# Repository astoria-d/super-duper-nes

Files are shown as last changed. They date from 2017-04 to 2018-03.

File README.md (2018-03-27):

# super-duper-nes

==========  Super-duper NES project!  ==========

This is a project that extends NES (Nintendo Entertainment System) with FPGA (DE0-CV board).

Architecture:
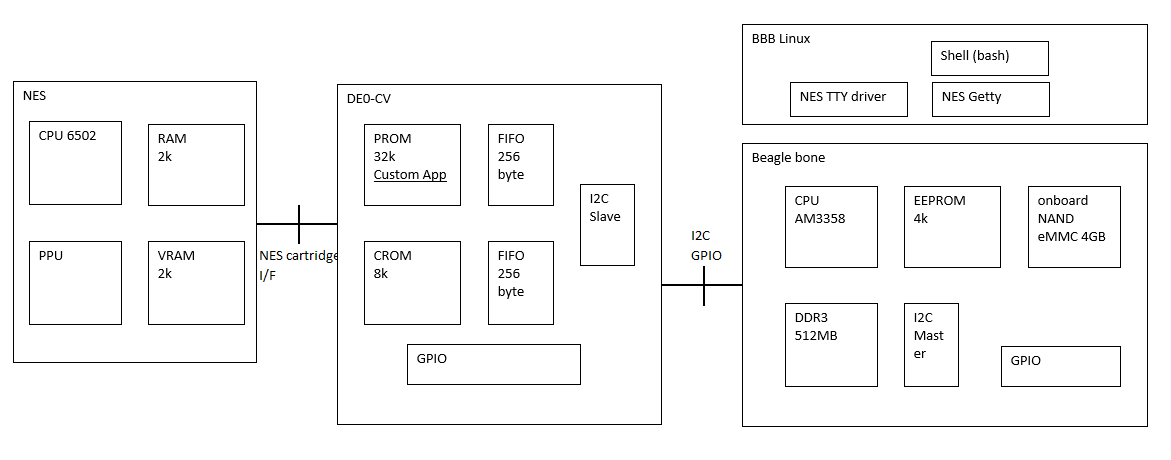
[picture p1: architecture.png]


User application ROM is deployed on FPGA ROM area. NES and DE0-CV board is connected through the NES 60 pin connector. User application has the Linux console screen. FPGA then has the I2C controler that connects FPGA and Linux board (Beagle bone black SBC). This will enable controling Linux from NES.

Demo:

<a href="http://www.youtube.com/watch?feature=player_embedded&v=RXIwD2YRAUA" target="_blank">super duper nes demo</a>

https://youtu.be/RXIwD2YRAUA

It can extend NES capability to infinity!

--astoria-d

-------

# source tree:
  
    top  
    |-- circuit-diagram             (obsolete)  
    |-- doc                         Technical documents.  
    |   |-- craft-work-diary        Electronic handcrafts pictures  
    |   |   |-- yyyymmdd  
    |   |   |-- ....  
    |   |   `-- yyyymmdd  
    |   `-- memo                    Linux work memo  
    |-- duper_cartridge             NES FPGA cartridge implementation (ROM, I2C slave, FIFO etc.)  
    |   `-- simulation              Modelsim scripts  
    |-- duper_linux                 Linux modules  
    |   |-- bbb_tty                 NES tty driver for BBB  
    |   |-- nes_shell  
    |   `-- tools  
    |-- duper_mapper                motonesemu mapper module.  
    |-- duper_rom                   NES cardridge ROM code  
    `-- test

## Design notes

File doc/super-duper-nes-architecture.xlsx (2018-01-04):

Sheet: overview
 |  | IDE 40 pins flat cable I/F
 | Fami con cartlidge I/F |  | I2C
 | 60 pin 2.54 mm pitch
 | dual side card edge
AV out

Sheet: block diagram
NES cartridge | I2C
I/F | GPIO

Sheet: memory map
CPU space | 0x10000
memory map | 0xfffa |  | reset vector
 | 0xfff8 |  | duper io reg | 0xfff9 | w: push fifo register
 |  |  |  |  | r: pop fifo register
 |  |  | prog rom | 0xfff8 | fifo status register
 |  |  | upper bank
 | 0xc000
 |  |  |  |  | firo status register
 |  |  |  | bit
 |  |  | prog rom | 0 | write fifo empty
 |  |  | lower bank | 1 | write fifo full
 |  |  |  | 2 | always 0
 | 0x8000 |  |  | 3 | always 0
 |  |  |  | 4 | read fifo empty
 |  |  | sram | 5 | read fifo full
 | 0x6000 |  |  | 6 | always 0
 |  |  |  | 7 | always 0
 |  |  | expantion rom
 | 0x4020
 | 0x4000 |  | io reg
 |  |  | mirror
 |  |  | 0x2000-0x2007
 | 0x2008
 | 0x2000 |  | io reg
 |  |  | mirror
 |  |  | 0x0000-0x07ff
 | 0x0800
 | 0x0200 |  | ram
 | 0x0100 | stack
 | 0x0000 | zp

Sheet: board-inter-connect
 |  |  |  |  |  |  |  |  |  |  |  |  | DE1
NES
 |  |  | FRONT |  |  | BACK
 |  |  | 1:GND | x | x | 31:Vcc
 | x | 2:PRG-A11 | 2:PRG-A11 | x | x | 32:M2
 | x | 3:PRG-A10 | 3:PRG-A10 | x | x | 33:PRG-A12 |  |  | x | 33:PRG-A12
 | x | 4:PRG-A9 | 4:PRG-A9 | x | x | 34:PRG-A13 |  |  | x | 34:PRG-A13
 | x | 5:PRG-A8 | 5:PRG-A8 | x | x | 35:PRG-A14 |  |  | x | 35:PRG-A14
 | x | 6:PRG-A7 | 6:PRG-A7 | x | x | 36:PRG-D7 |  | x | 36:PRG-D7 |  |  |  |  | i2c_sda | i2c_scl | NC | NC | NC | 3.3V | 47:~CHR-WE | 50:CHR-A7 | 51:CHR-A8 | 52:CHR-A9 | 53:CHR-A10 | 54:CHR-A11 | 55:CHR-A12 | 56~:CHR-A13 | 5v | NC | 57:CHR-D7 | 58:CHR-D6 | 59:CHR-D5 | 60:CHR-D4
 | x | 7:PRG-A6 | 7:PRG-A6 | x | x | 37:PRG-D6 |  | x | 37:PRG-D6 |  | x | 32:M2 |  | x | x | x | x | x | x | x | x | x | x | x | x | x | x | x | x | x | x | x | x
 | x | 8:PRG-A5 | 8:PRG-A5 | x | x | 38:PRG-D5 |  | x | 38:PRG-D5 |  | x | 44:~PRG-CE |  | x | x | x | x | x | x | x | x | x | x | x | x | x | x | x | x | x | x | x | x
 | x | 9:PRG-A4 | 9:PRG-A4 | x | x | 39:PRG-D4 |  | x | 39:PRG-D4 |  |  |  |  | bbb_f_empty | nes_f_full | NC | NC | NC | GND | 17:~CHR-OE | 19:CHR-A6 | 20:CHR-A5 | 21:CHR-A4 | 22:CHR-A3 | 23:CHR-A2 | 24:CHR-A1 | 25:CHR-A0 | GND | NC | 29:CHR-D0 | 28:CHR-D1 | 27:CHR-D2 | 26:CHR-D3
x | 10:PRG-A3 |  | 10:PRG-A3 | x | x | 40:PRG-D3 |  | x | 40:PRG-D3
x | 11:PRG-A2 |  | 11:PRG-A2 | x | x | 41:PRG-D2 |  | x | 41:PRG-D2
x | 12:PRG-A1 |  | 12:PRG-A1 | x | x | 42:PRG-D1 |  | x | 42:PRG-D1 |  |  |  |  | NC | NC | NC | NC | 44:~PRG-CE | 3.3V | 2:PRG-A11 | 3:PRG-A10 | 4:PRG-A9 | 5:PRG-A8 | 6:PRG-A7 | 7:PRG-A6 | 8:PRG-A5 | 9:PRG-A4 | 5v | NC | 36:PRG-D7 | 37:PRG-D6 | 38:PRG-D5 | 39:PRG-D4
x | 13:PRG-A0 |  | 13:PRG-A0 | x | x | 43:PRG-D0 |  | x | 43:PRG-D0 |  |  | i2c_sda |  | 34 | 32 | 30 | 28 | 26 |  | 24 | 22 | 20 | 18 | 16 | 14 | 12 | 10 |  | 8 | 6 | 4 | 2 | 0
x | 14:PRG-R/~W |  | 14:PRG-R/~W | x | x | 44:~PRG-CE |  |  |  |  |  | i2c_scl
 |  |  | 15:~IRQ N/C (Out) | x | x | 45:Sound In C46 |  |  |  |  |  |  |  | x | x | x | x | x | x | x | x | x | x | x | x | x | x | x | x | x | x | x | x
 |  |  | 16:GND | x | x | 46:Sound Out C45 |  |  |  |  |  |  |  | x | x | x | x | x | x | x | x | x | x | x | x | x | x | x | x | x | x | x | x
 |  |  | 17:~CHR-OE | x | x | 47:~CHR-WE
 |  |  | 18:VRAM-A10 | x | x | 48:~VRAM-CE |  |  |  |  |  |  |  | 35 | 33 | 31 | 29 | 27 |  | 25 | 23 | 21 | 19 | 17 | 15 | 13 | 11 |  | 9 | 7 | 5 | 3 | 1
 | x | 17:~CHR-OE | 19:CHR-A6 | x | x | 49:CHR-A13 |  |  | 47:~CHR-WE |  |  |  |  | NC | NC | NC | NC | 32:M2 | GND | 10:PRG-A3 | 11:PRG-A2 | 12:PRG-A1 | 13:PRG-A0 | 14:PRG-R/~W | 35:PRG-A14 | 34:PRG-A13 | 35:PRG-A12 | GND | NC | 40:PRG-D3 | 41:PRG-D2 | 42:PRG-D1 | 43:PRG-D0
 | x | 19:CHR-A6 | 20:CHR-A5 | x | x | 50:CHR-A7 |  |  | 50:CHR-A7
 | x | 20:CHR-A5 | 21:CHR-A4 | x | x | 51:CHR-A8 |  |  | 51:CHR-A8
 | x | 21:CHR-A4 | 22:CHR-A3 | x | x | 52:CHR-A9 |  |  | 52:CHR-A9
 | x | 22:CHR-A3 | 23:CHR-A2 | x | x | 53:CHR-A10 |  | x | 53:CHR-A10
 | x | 23:CHR-A2 | 24:CHR-A1 | x | x | 54:CHR-A11 |  | x | 54:CHR-A11
 | x | 24:CHR-A1 | 25:CHR-A0 | x | x | 55:CHR-A12 |  | x | 55:CHR-A12
 | x | 25:CHR-A0 | 26:CHR-D0 | x | x | 56~:CHR-A13 |  | x | 56~:CHR-A13
x |  | 26:CHR-D0 | 27:CHR-D1 | x | x | 57:CHR-D7 | x |  | 57:CHR-D7
x |  | 27:CHR-D1 | 28:CHR-D2 | x | x | 58:CHR-D6 | x |  | 58:CHR-D6
x |  | 28:CHR-D2 | 29:CHR-D3 | x | x | 59:CHR-D5 | x |  | 59:CHR-D5
x |  | 29:CHR-D3 | 30:Vcc | x | x | 60:CHR-D4 | x |  | 60:CHR-D4

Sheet: bus
 | /data
 | /addr
 |  | /i2c_data_in | /empty | /full
 |  | /i2c_data_out
 |  | /scl | /full | /empty
 |  | /sda
 | /data
 | /addr
/composite

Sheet: duper cartridge rtl
 |  |  |  | linux command send |  |  |  |  |  |  |  |  |  |  |  |  |  |  |  |  |  |  |  |  |  |  | linux terminal
 |  |  |  | console display |  |  |  |  |  |  |  |  |  |  |  |  |  |  |  |  |  |  |  |  |  |  | i2c i/o
 | composite out |  |  |  |  |  |  |  | rom read |  |  |  |  |  |  |  |  |  | fifo status read (gpio)
 |  |  |  |  |  |  |  |  | fifo status read |  |  |  |  |  |  |  |  |  | i2c data read
 |  |  |  |  |  |  |  |  | fifo read |  |  |  |  |  |  |  |  |  | i2c data write
 | keypad input |  |  |  |  |  |  |  | fifo write
 |  |  |  |  |  |  |  |  |  |  |  |  |  | duper state machine
de0-cv base clock = 50 MHz |  |  |  |  |  |  |  | x 27.93 times
nes cpu clock = 1.789773 MHz
 |  |  |  |  |  |  |  |  |  |  |  |  |  |  | x 500 times
i2c clock = 100 KHz |  |  |  |  |  |  |  |  | x 17.89 times
 |  | base clock
 |  | nes clock
instruction |  |  | nop |  |  |  |  |  |  |  |  |  |  |  |  |  | lda $50 |  |  |  |  |  |  |  |  |  |  |  |  |  |  |  |  |  |  |  |  | lda $ff25
state machie |  |  | rom read |  |  |  |  |  |  | idle |  |  |  |  |  |  | rom read |  |  |  |  |  |  | rom read |  |  |  |  |  |  | idle |  |  |  |  |  |  | rom read |  |  |  |  |  |  | rom read
 |  |  |  |  |  |  |  |  |  |  |  |  |  |  |  |  |  |  |  |  |  |  |  |  |  |  |  |  |  |  |  |  |  |  |  |  | idle
 |  |  |  |  |  |  |  |  |  |  |  |  |  |  |  |  |  |  |  |  |  |  |  |  |  |  |  |  |  |  |  |  |  |  |  | fifo push
 |  | i2c clock
 |  |  |  |  | i2c transfer |  |  |  |  |  |  |  |  |  |  |  |  |  |  |  |  |  |  |  |  |  |  |  |  |  |  |  |  |  |  | i2c done
 |  |  |  |  | rom | idle | rom | idle | rom | idle | rom | idle | rom | idle | rom | idle | rom | idle | rom | idle | rom | idle | rom | idle | rom | idle | rom | idle | rom | idle | rom | idle | rom | idle | rom | idle | rom | idle | rom | idle | rom | idle | rom | idle
 |  |  |  |  | i2c xfer |  |  |  |  |  |  |  |  |  |  |  |  |  |  |  |  |  |  |  |  |  | i2c ack |  |  |  |  |  |  |  |  |  |  |  |  |  | i2c idle

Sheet: fifo
fifo
 | init:
 |  | fifo tail
 |  |  |  |  |  |  |  |  | size = 0
 |  |  |  |  |  |  |  |  | empty = 1
 |  | fifo head |  |  |  |  |  |  | full = 0 | NES > BBB
 | push x 4
 |  |  |  |  | fifo tail
 |  |  |  |  |  |  |  |  | size = 4
 |  |  |  |  |  |  |  |  | empty = 0
 |  | fifo head |  |  |  |  |  |  | full = 0
 |  |  |  |  |  |  |  |  |  | duper state machine
 | pop x 2
 |  |  |  |  | fifo tail
 |  |  |  |  |  |  |  |  | size = 2
 |  |  |  |  |  |  |  |  | empty = 0
 |  |  | fifo head |  |  |  |  |  | full = 0
 | pop x 2
 |  |  |  |  | fifo tail
 |  |  |  |  |  |  |  |  | size = 0
 |  |  |  |  |  |  |  |  | empty = 1 |  | fifo head set
 |  |  |  |  | fifo head |  |  |  | full = 0
 | push x 10 |  |  |  |  |  |  |  |  |  |  | notify via gpio
 |  |  |  |  |  |  | ・・・・・・ | fifo tail
 |  |  |  |  |  |  |  |  | size = 10
 |  |  |  |  |  |  |  |  | empty = 0
 |  |  |  |  | fifo head |  |  |  | full = 0
 | push x 246
 |  |  |  | fifo tail
 |  |  |  |  |  |  |  |  | size = 256
 |  |  |  |  |  |  |  |  | empty = 0
 |  |  |  |  | fifo head |  |  |  | full = 1
 | pop x 2
 |  |  |  | fifo tail
 |  |  |  |  |  |  |  |  | size = 254
 |  |  |  |  |  |  |  |  | empty = 0
 |  |  |  |  |  | fifo head |  |  | full = 0
 | pop x 254
 |  |  |  | fifo tail
 |  |  |  |  |  |  |  |  | size = 0
 |  |  |  |  |  |  |  |  | empty = 1
 |  |  |  | fifo head |  |  |  |  | full = 0

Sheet: bus seq
 |  |  | Address = 0x44 ( 100 0100)
 | Start seq |  |  |  |  | 1 |  |  |  |  | 0 |  |  |  | 0 |  |  |  | 0 |  |  |  | 1 | 0 | 0 | R/W = 0 (Write)
SDA
SCL
 |  |  |  |  | 1 | 0 | 0 | 0 |  |  |  |  |  |  |  | 0 | 0 |  |  | 0 |  | ack
 |  | S | 1 | 0 |  |  |  |  | 0 | r | ack | P | S | 0 | 0 |  |  | 0 | 0 |  | 0

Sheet: bbb goio
https://vadl.github.io/beagleboneblack/2016/07/29/setting-up-bbb-gpio
 | GPIO Numbering Scheme
 | The gpio pins of the bbb are grouped into 3 groups of 32: GPIO0, GPIO1, and GPIO2. An individual pin can be refered to using the convention GPIOX_Y where X is its gpio register and Y is its number within that register. However, all references to a particular pin made in software instead uses its absolute pin number! A gpio’s absolute pin number is calculated in the following manner: Z = 32*X + Y where X is again the gpio register and Yis the position within that register.
 | i.e. GPIO2_24 is 32*2+24, making it GPIO_88. If this pin were to be referenced anywhere in software, the user would use the number 88, not 24!
 |  |  |  | nes_f_full
 |  | bbb_f_empty |  |  |  |  | bbb_f_empty = gpio115
 |  |  |  |  |  |  | nes_f_full = gpio49
 |  | 27 | 25 | 23
 |  | gpio1_17 = 49
 |  |  |  |  | 32 | 17
 |  | gpio3_19 = 115 |  |  | 96 | 19

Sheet: bit rate
i2c | clock | 100 kHz
addr | 8clk+1ack
data | 8clk+1ack |  | 1byte = 18 clks.
 |  |  | 1 clock = 1 / 100 / 1000 = 10 usec
 |  |  | 1 byte = 180 usec
 |  |  | 1 / 180 * 1000000 | 5555.555556
 |  |  | 5.5 k byte / sec
 |  |  |  |  | i2c is much faster!!
nes frame rate
 | 30 | Hz
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

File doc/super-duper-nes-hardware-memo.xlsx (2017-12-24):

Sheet: Connection
 |  | pin header | pin socket |  | QI connector
 |  |  |  | cable w/ pin socket
max 60 lines.
 | I2C
 | 4 lines

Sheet: cartridge
カートリッジコネクタピンアサイン |  |  | http://wiki.nesdev.com/w/index.php/Cartridge_connector
表 | 裏 |  |  | ------- |  |  |  |  | おおよそ上半分がCPUからのアドレスバスとデータバス
1:GND | 31:Vcc |  | GND -- | |01 31| | -- +5V |  |  |  | IRQやオーディオなどを挟んで下半分がPPUのアドレスバスとデータバス
2:PRG-A11 | 32:??? N/C |  | CPU A11 -> | |02 32| | <- M2 |  |  |  | φ2(M2とも)はシステムクロック
3:PRG-A10 | 33:PRG-A12 |  | CPU A10 -> | |03 33| | <- CPU A12 |  |  |  | SOUND INはAPU(2A03)からのサウンド出力。
4:PRG-A9 | 34:PRG-A13 |  | CPU A9 -> | |04 34| | <- CPU A13 |  |  |  | SOUND OUTはカセット側に拡張音源が乗っていればSOUND INとミックスして出力。
5:PRG-A8 | 35:PRG-A14 |  | CPU A8 -> | |05 35| | <- CPU A14 |  |  |  | 特になければそのままOUTに直結する。
6:PRG-A7 | 36:PRG-D7 |  | CPU A7 -> | |06 36| | <> CPU D7 |  |  |  | ピッチは2.54mm
7:PRG-A6 | 37:PRG-D6 |  | CPU A6 -> | |07 37| | <> CPU D6 |  |  |  | 基板厚は1.2mm
8:PRG-A5 | 38:PRG-D5 |  | CPU A5 -> | |08 38| | <> CPU D5
9:PRG-A4 | 39:PRG-D4 |  | CPU A4 -> | |09 39| | <> CPU D4
10:PRG-A3 | 40:PRG-D3 |  | CPU A3 -> | |10 40| | <> CPU D3
11:PRG-A2 | 41:PRG-D2 |  | CPU A2 -> | |11 41| | <> CPU D2
12:PRG-A1 | 42:PRG-D1 |  | CPU A1 -> | |12 42| | <> CPU D1
13:PRG-A0 | 43:PRG-D0 |  | CPU A0 -> | |13 43| | <> CPU D0
14:PRG-R/~W | 44:~PRG-CE |  | CPU R/W -> | |14 44| | <- /ROMSEL (/A15 + /M2)
15:~IRQ N/C (Out) | 45:Sound In C46 |  | /IRQ <- | |15 45| | <- Audio from 2A03
16:GND | 46:Sound Out C45 |  | GND -- | |16 46| | -> Audio to RF
17:~CHR-OE | 47:~CHR-WE |  | PPU /RD -> | |17 47| | <- PPU /WR
18:VRAM-A10 | 48:~VRAM-CE | >> | CIRAM A10 <- | |18 48| | -> CIRAM /CE
19:CHR-A6 | 49:CHR-A13 |  | PPU A6 -> | |19 49| | <- PPU A13
20:CHR-A5 | 50:CHR-A7 |  | PPU A5 -> | |20 50| | <- PPU A7
21:CHR-A4 | 51:CHR-A8 |  | PPU A4 -> | |21 51| | <- PPU A8
22:CHR-A3 | 52:CHR-A9 |  | PPU A3 -> | |22 52| | <- PPU A9
23:CHR-A2 | 53:CHR-A10 |  | PPU A2 -> | |23 53| | <- PPU A10
24:CHR-A1 | 54:CHR-A11 |  | PPU A1 -> | |24 54| | <- PPU A11 | <<
25:CHR-A0 | 55:CHR-A12 |  | PPU A0 -> | |25 55| | <- PPU A12
26:CHR-D0 | 56~:CHR-A13 |  | PPU D0 <> | |26 56| | <- PPU /A13
27:CHR-D1 | 57:CHR-D7 |  | PPU D1 <> | |27 57| | <> PPU D7
28:CHR-D2 | 58:CHR-D6 |  | PPU D2 <> | |28 58| | <> PPU D6
29:CHR-D3 | 59:CHR-D5 |  | PPU D3 <> | |29 59| | <> PPU D5
30:Vcc | 60:CHR-D4 |  | +5V -- | |30 60| | <> PPU D4
 |  |  |  | -------
 |  |  |  |  |  | Burgur time iNES dump
 |  |  |  |  |  |  |  |  |  | https://wiki.nesdev.com/w/index.php/Mask_ROM_pinout
 |  |  |  | ------- |  |  | ------- |  |  | RROM Non-standard 64-kbit CHR pinout
 |  |  | GND -- | |01 31| |  |  | |01 31| | -- +5V |  | ---_---
 |  |  | CPU A11 -> | |02 32| |  |  | |02 32| | <- M2 |  | A7 - |01 28| - +5V
 |  |  | CPU A10 -> | |03 33| |  |  | |03 33| | <- CPU A12 |  | A6 - |02 27| - A8
 |  |  | CPU A9 -> | |04 34| |  |  | |04 34| | <- CPU A13 |  | A5 - |03 26| - A9
 |  |  | CPU A8 -> | |05 35| |  |  | |05 35| | <- CPU A14 |  | A4 - |04 25| - A12
 |  |  | CPU A7 -> | |06 36| |  |  | |06 36| | <> CPU D7 |  | A3 - |05 24| - /CE
 |  |  | CPU A6 -> | |07 37| |  |  | |07 37| | <> CPU D6 |  | +5V - |06 23| - NC
 |  |  | CPU A5 -> | |08 38| |  |  | |08 38| | <> CPU D5 |  | +5V - |07 22| - /OE
 |  |  | CPU A4 -> | |09 39| |  |  | |09 39| | <> CPU D4 |  | A2 - |08 21| - A10
 |  |  | CPU A3 -> | |10 40| |  |  | |10 40| | <> CPU D3 |  | A1 - |09 20| - A11
 |  |  | CPU A2 -> | |11 41| |  |  | |11 41| | <> CPU D2 |  | A0 - |10 19| - D7
 |  |  | CPU A1 -> | |12 42| |  |  | |12 42| | <> CPU D1 |  | D0 - |11 18| - D6
 |  |  | CPU A0 -> | |13 43| |  |  | |13 43| | <> CPU D0 |  | D1 - |12 17| - D5
 |  |  | CPU R/W -> | |14 44| |  |  | |14 44| | <- /ROMSEL (/A15 + /M2) |  | D2 - |13 16| - D4
 |  |  | /IRQ <- | |15 45| |  |  | |15 45| | <- Audio from 2A03 |  | GND - |14 15| - D3
 |  |  | GND -- | |16 46| |  |  | |16 46| | -> Audio to RF |  | -------
 |  |  | PPU /RD -> | |17 47| |  |  | |17 47| | <- PPU /WR
 |  |  | CIRAM A10 <- | |18 48| |  |  | |18 48| | -> CIRAM /CE
 |  |  | PPU A6 -> | |19 49| |  |  | |19 49| | <- PPU A13
 |  |  | PPU A5 -> | |20 50| |  |  | |20 50| | <- PPU A7
 |  |  | PPU A4 -> | |21 51| |  |  | |21 51| | <- PPU A8
 |  |  | PPU A3 -> | |22 52| |  |  | |22 52| | <- PPU A9 |  |  | https://wiki.nesdev.com/w/index.php/Mirroring
 |  |  | PPU A2 -> | |23 53| |  |  | |23 53| | <- PPU A10
 |  |  | PPU A1 -> | |24 54| |  |  | |24 54| | <- PPU A11 |  |  |  | To configure a cartridge board for horizontal mirroring, connect PPU A11 to CIRAM A10. On cartridge boards made by Nintendo, this is selected by shorting the "V" solder pad (for "vertical arrangement"). Note using inverse logic may make more sense, "Leaving the 'H' jumper open gives horizontal mirroring" on Nintendo boards.
 |  |  | PPU A0 -> | |25 55| |  |  | |25 55| | <- PPU A12
 |  |  | PPU D0 <> | |26 56| |  |  | |26 56| | <- PPU /A13
 |  |  | PPU D1 <> | |27 57| |  |  | |27 57| | <> PPU D7
 |  |  | PPU D2 <> | |28 58| |  |  | |28 58| | <> PPU D6
 |  |  | PPU D3 <> | |29 59| |  |  | |29 59| | <> PPU D5
 |  |  | +5V -- | |30 60| |  |  | |30 60| | <> PPU D4
 |  |  |  | ------- |  |  | -------

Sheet: gpio
 |  | JP1
 | 1 |  | x | x | 2
 | 3 |  | x | x | 4
 | 5 |  | x | x | 6
 | 7 |  | x | x | 8
 | 9 |  | x | x | 10
VCC5 | 11 |  | x | x | 12 | GND
 | 13 |  | x | x | 14
 | 15 |  | x | x | 16
 | 17 |  | x | x | 18
 | 19 |  | x | x | 20
 | 21 |  | x | x | 22
 | 23 |  | x | x | 24
 | 25 |  | x | x | 26
 | 27 |  | x | x | 28
VCC33 | 29 |  | x | x | 30 | GND
 | 31 |  | x | x | 32
 | 33 |  | x | x | 34
 | 35 |  | x | x | 36
 | 37 |  | x | x | 38
 | 39 |  | x | x | 40

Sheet: nes-fpga-interface
 | nes side |  |  | fpga side
 | vcc=5v, vss=0v
 | vil | min | -0.3 | vil | min | -0.3
 |  | max | 0.4 |  | max | 0.8
 | vih | min | 2.4 | vih | min | 1.7
 |  | max | 5 |  | max | 3.6
 | input threshold | low | 0.8 | input threshold | low | 0.8
 |  | high | 2 |  | high | 1.7
 | vol | min | - | vol | min | -
 |  | max | 0.4 |  | max | 0.2
 | voh | min | 2.4 | voh | min | 3.1
 |  | max | - |  | max | -
 | NES |  |  |  |  |  |  | FPGA
(v) |  |  |  |  |  |  | (v)
5.0 |  |  |  |  |  |  | 5.0
4.8 |  |  |  |  |  |  | 4.8
4.6 |  |  |  |  |  |  | 4.6
4.4 |  |  |  |  |  |  | 4.4
4.2 |  |  |  |  |  |  | 4.2
4.0 |  |  |  |  |  |  | 4.0
3.8 |  |  |  |  |  | input range | 3.8
3.6 |  |  |  |  |  |  | 3.6
3.4 |  |  |  |  |  |  | 3.4
3.2 |  |  |  |  |  |  | 3.2
3.0 |  |  |  |  |  |  | 3.0 |  |  | output range
2.8 |  |  |  |  |  |  | 2.8
2.6 |  |  |  |  |  |  | 2.6
2.4 |  |  |  |  |  |  | 2.4
2.2 |  |  |  |  |  |  | 2.2
2.0 |  |  |  |  | input threshold |  | 2.0
1.8 |  |  |  |  |  |  | 1.8
1.6 |  |  |  |  |  |  | 1.6
1.4 |  |  |  |  |  |  | 1.4
1.2 |  |  |  |  |  |  | 1.2
1.0 |  |  |  |  |  |  | 1.0
0.8 |  |  |  |  |  |  | 0.8
0.6 |  |  |  |  | input threshold |  | 0.6
0.4 |  |  |  |  |  |  | 0.4
0.2 |  |  |  |  |  |  | 0.2
0.0 |  |  |  |  |  | input range | 0.0 |  |  | output range
-0.2 |  |  |  |  |  |  | -0.2
-0.4 |  |  |  |  |  |  | -0.4
(v) |  |  |  |  |  |  | (v)
5.0 |  |  |  |  |  |  | 5.0
4.8 |  |  |  |  |  |  | 4.8
4.6 |  |  |  |  |  |  | 4.6
4.4 |  |  |  |  |  |  | 4.4
4.2 |  |  |  |  |  |  | 4.2
4.0 |  |  |  |  |  |  | 4.0
3.8 |  |  |  |  |  |  | 3.8
3.6 |  |  |  |  |  | output range | 3.6
3.4 |  |  |  |  |  |  | 3.4
3.2 |  |  |  |  |  |  | 3.2
3.0 |  |  |  |  |  |  | 3.0
2.8 |  |  |  |  |  |  | 2.8
2.6 |  |  |  |  |  |  | 2.6 |  |  | input range
2.4 |  |  |  |  |  |  | 2.4
2.2 |  |  |  |  |  |  | 2.2
2.0 |  |  |  |  |  |  | 2.0
1.8 |  |  |  |  |  |  | 1.8 |  | input threshold
1.6 |  |  |  |  |  |  | 1.6
1.4 |  |  |  |  |  |  | 1.4
1.2 |  |  |  |  |  |  | 1.2
1.0 |  |  |  |  |  |  | 1.0
0.8 |  |  |  |  |  |  | 0.8
0.6 |  |  |  |  |  |  | 0.6 |  | input threshold
0.4 |  |  |  |  |  |  | 0.4
0.2 |  |  |  |  |  |  | 0.2 |  |  | input range
0.0 |  |  |  |  |  | output range | 0.0
-0.2 |  |  |  |  |  |  | -0.2
-0.4 |  |  |  |  |  |  | -0.4
 |  |  |  |  |  |  |  |  | //

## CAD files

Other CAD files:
duper_cartridge/duper_cartridge.stp
test/level_shift_test01/level_shift_test01.stp
test/level_shift_test01/level_shift_test01_auto_stripped.stp

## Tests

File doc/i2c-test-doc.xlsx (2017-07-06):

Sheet: general study
32k eeprom implemented
 |  |  |  | cape eeprom specification
[dmotooka@ *BBB* :~] i2cdetect -l
i2c-0 | i2c | OMAP I2C adapter | I2C adapter
i2c-2 | i2c | OMAP I2C adapter | I2C adapter
[dmotooka@ *BBB* :~] sudo i2cdetect -y -r 0
0 1 2 3 4 5 6 7 8 9 a b c d e f
00: -- -- -- -- -- -- -- -- -- -- -- -- --
10: -- -- -- -- -- -- -- -- -- -- -- -- -- -- -- --
20: -- -- -- -- UU -- -- -- -- -- -- -- -- -- -- --
30: -- -- -- -- UU -- -- -- -- -- -- -- -- -- -- --
40: -- -- -- -- -- -- -- -- -- -- -- -- -- -- -- --
50: UU -- -- -- -- -- -- -- -- -- -- -- -- -- -- --
60: -- -- -- -- -- -- -- -- -- -- -- -- -- -- -- --
70: UU -- -- -- -- -- -- --
[dmotooka@ *BBB* :~] sudo i2cdetect -y -r 1
Error: Could not open file `/dev/i2c-1' or `/dev/i2c/1': No such file or directory
[dmotooka@ *BBB* :~] sudo i2cdetect -y -r 2
0 1 2 3 4 5 6 7 8 9 a b c d e f
00: -- -- -- -- -- -- -- -- -- -- -- -- --
10: -- -- -- -- -- -- -- -- -- -- -- -- -- -- -- --
20: -- -- -- -- -- -- -- -- -- -- -- -- -- -- -- --
30: -- -- -- -- -- -- -- -- -- -- -- -- -- -- -- --
40: -- -- -- -- -- -- -- -- -- -- -- -- -- -- -- --
50: -- -- -- -- UU UU UU UU -- -- -- -- -- -- -- --
60: -- -- -- -- -- -- -- -- -- -- -- -- -- -- -- --
70: -- -- -- -- -- -- -- --
[dmotooka@ *BBB* :~] sudo hexdump -C /sys/bus/i2c/devices/0-0050/eeprom
00000000 aa 55 33 ee 41 33 33 35 42 4e 4c 54 30 30 43 30 |.U3.A335BNLT00C0
00000010 33 31 31 35 42 42 42 4b 30 42 43 42 ff ff ff ff |3115BBBK0BCB....
00000020 ff ff ff ff ff ff ff ff ff ff ff ff ff ff ff ff |................
[dmotooka@ *BBB* :/sys/bus/i2c/devices/i2c-0] ll
total 0
drwxr-xr-x 8 root root 0 Mar 1 2015 0-0024
drwxr-xr-x 3 root root 0 Jun 25 04:27 0-0034
drwxr-xr-x 4 root root 0 Mar 1 2015 0-0050
drwxr-xr-x 4 root root 0 Jun 25 04:27 0-0070
--w------- 1 root root 4096 Jun 25 06:19 delete_device
lrwxrwxrwx 1 root root 0 Jun 25 06:19 device -> ../../44e0b000.i2c
drwxr-xr-x 3 root root 0 Jun 25 03:33 i2c-dev
-r--r--r-- 1 root root 4096 Jun 25 06:19 name
--w------- 1 root root 4096 Jun 25 06:19 new_device
lrwxrwxrwx 1 root root 0 Jun 25 06:19 of_node -> ../../../../../firmware/devicetree/base/ocp/i2c@44e0b000
drwxr-xr-x 2 root root 0 Jun 25 06:19 power
lrwxrwxrwx 1 root root 0 Jun 25 06:19 subsystem -> ../../../../../bus/i2c
-rw-r--r-- 1 root root 4096 Jun 25 06:19 uevent
[dmotooka@ *BBB* :/sys/bus/i2c/devices/i2c-0] l 0-00*
0-0024:
driver@ modalias of_node@ regulator/ tps65217-bl/ tps65217-pmic/
input/ name power/ subsystem@ tps65217-charger/ uevent
0-0034:
driver@ modalias name power/ subsystem@ uevent
0-0050:
0-00500/ driver@ eeprom modalias name of_node@ power/ subsystem@ uevent
0-0070:
driver@ hdmi-audio-codec.2.auto/ modalias name of_node@ power/ subsystem@ uevent
[dmotooka@ *BBB* :/sys/bus/i2c/devices/i2c-2] ls 2-00*/
2-0054/:
2-00540 driver eeprom modalias name of_node power subsystem uevent
2-0055/:
2-00550 driver eeprom modalias name of_node power subsystem uevent
2-0056/:
2-00560 driver eeprom modalias name of_node power subsystem uevent
2-0057/:
2-00570 driver eeprom modalias name of_node power subsystem uevent
[dmotooka@ *BBB* :/sys/bus/i2c/devices/i2c-2] sudo hexdump -C /sys/bus/i2c/devices/2-0054/eeprom | head
hexdump: /sys/bus/i2c/devices/2-0054/eeprom: Connection timed out

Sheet: pins
Table 11 lists the signals on connector P9. Other signals can be connected to this
connector based on setting the pin mux on the processor, but this is the default settings on
power up.
5.3.5 I2C | 4.2 memory
There are two I2C Ports on the expansion header, I2C1 and I2C2. I2C2 is used for the | A single 32KB EEPROM is provided on I2C0 that holds the board information. This
EEPROMS on the expansion boards and must always be accessible. SW should never | information includes board name, serial number, and revision information. Unused areas
mess with these signals. Other components on a Cape can use this bus as long as it does | can be used by SW applications if desired.
not conflict with the base addresses of the Capes.

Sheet: omap ref
[dmotooka@ *BBB* :/sys/bus/i2c/devices] ll
lrwxrwxrwx 1 root root 0 Jun 25 04:27 i2c-0 -> ../../../devices/platform/ocp/44e0b000.i2c/i2c-0
lrwxrwxrwx 1 root root 0 Jun 25 04:27 i2c-2 -> ../../../devices/platform/ocp/4819c000.i2c/i2c-2

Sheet: impl
[dmotooka@ *BBB* :/sys/bus/i2c/devices] sudo i2cdetect -l
i2c-0 | i2c | OMAP I2C adapter | I2C adapter
i2c-2 | i2c | OMAP I2C adapter | I2C adapter
[dmotooka@ *BBB* :/sys/bus/i2c/devices] sudo i2cdetect -r 0
WARNING! This program can confuse your I2C bus, cause data loss and worse!
I will probe file /dev/i2c-0 using read byte commands.
I will probe address range 0x03-0x77.
Continue? [Y/n]
0 1 2 3 4 5 6 7 8 9 a b c d e f
00: -- -- -- -- -- -- -- -- -- -- -- -- --
10: -- -- -- -- -- -- -- -- -- -- -- -- -- -- -- --
20: -- -- -- -- UU -- -- -- -- -- -- -- -- -- -- --
30: -- -- -- -- UU -- -- -- -- -- -- -- -- -- -- --
40: -- -- -- -- -- -- -- -- -- -- -- -- -- -- -- --
50: UU -- -- -- -- -- -- -- -- -- -- -- -- -- -- --
60: -- -- -- -- -- -- -- -- -- -- -- -- -- -- -- --
70: UU -- -- -- -- -- -- --
[dmotooka@ *BBB* :/sys/bus/i2c/devices] sudo i2cdetect -r 1
Error: Could not open file `/dev/i2c-1' or `/dev/i2c/1': No such file or directory
[dmotooka@ *BBB* :/sys/bus/i2c/devices] sudo i2cdetect -r 2
WARNING! This program can confuse your I2C bus, cause data loss and worse!
I will probe file /dev/i2c-2 using read byte commands.
I will probe address range 0x03-0x77.
Continue? [Y/n]
0 1 2 3 4 5 6 7 8 9 a b c d e f
00: -- -- -- -- -- -- -- -- -- -- -- -- --
10: -- -- -- -- -- -- -- -- -- -- -- -- -- -- -- --
20: -- -- -- -- -- -- -- -- -- -- -- -- -- -- -- --
30: -- -- -- -- -- -- -- -- -- -- -- -- -- -- -- --
40: -- -- -- -- -- -- -- -- -- -- -- -- -- -- -- --
50: -- -- -- -- UU UU UU UU -- -- -- -- -- -- -- --
60: -- -- -- -- -- -- -- -- -- -- -- -- -- -- -- --
70: -- -- -- -- -- -- -- --
[dmotooka@ *BBB* :/sys/bus/i2c/devices]
if you use default kernel….
[dmotooka@ *BBB* :~] i2cdetect -l
i2c-0 | i2c | OMAP I2C adapter | I2C adapter
i2c-1 | i2c | OMAP I2C adapter | I2C adapter
[dmotooka@ *BBB* :~] sudo sh -c "echo BB-I2C1 > /sys/devices/bone_capemgr.9/slots"
[dmotooka@ *BBB* :~] i2cdetect -l
i2c-0 | i2c | OMAP I2C adapter | I2C adapter
i2c-1 | i2c | OMAP I2C adapter | I2C adapter
i2c-2 | i2c | OMAP I2C adapter | I2C adapter
[dmotooka@ *BBB* :/sys/bus/i2c/devices] ll i2c-*
lrwxrwxrwx 1 root root 0 Jul 1 11:39 i2c-0 -> ../../../devices/ocp.3/44e0b000.i2c/i2c-0
lrwxrwxrwx 1 root root 0 Jul 1 11:39 i2c-1 -> ../../../devices/ocp.3/4819c000.i2c/i2c-1
lrwxrwxrwx 1 root root 0 Jul 1 11:45 i2c-2 -> ../../../devices/ocp.3/4802a000.i2c/i2c-2
[dmotooka@ *BBB* :/sys/bus/i2c/devices] i2cdetect -r 0
WARNING! This program can confuse your I2C bus, cause data loss and worse!
I will probe file /dev/i2c-0 using read byte commands.
I will probe address range 0x03-0x77.
Continue? [Y/n]
0 1 2 3 4 5 6 7 8 9 a b c d e f
00: -- -- -- -- -- -- -- -- -- -- -- -- --
10: -- -- -- -- -- -- -- -- -- -- -- -- -- -- -- --
20: -- -- -- -- UU -- -- -- -- -- -- -- -- -- -- --
30: -- -- -- -- UU -- -- -- -- -- -- -- -- -- -- --
40: -- -- -- -- -- -- -- -- -- -- -- -- -- -- -- --
50: UU -- -- -- -- -- -- -- -- -- -- -- -- -- -- --
60: -- -- -- -- -- -- -- -- -- -- -- -- -- -- -- --
70: UU -- -- -- -- -- -- --
[dmotooka@ *BBB* :/sys/bus/i2c/devices] i2cdetect -r 1
WARNING! This program can confuse your I2C bus, cause data loss and worse!
I will probe file /dev/i2c-1 using read byte commands.
I will probe address range 0x03-0x77.
Continue? [Y/n]
0 1 2 3 4 5 6 7 8 9 a b c d e f
00: -- -- -- -- -- -- -- -- -- -- -- -- --
10: -- -- -- -- -- -- -- -- -- -- -- -- -- -- -- --
20: -- -- -- -- -- -- -- -- -- -- -- -- -- -- -- --
30: -- -- -- -- -- -- -- -- -- -- -- -- -- -- -- --
40: -- -- -- -- -- -- -- -- -- -- -- -- -- -- -- --
50: -- -- -- -- UU UU UU UU -- -- -- -- -- -- -- --
60: -- -- -- -- -- -- -- -- -- -- -- -- -- -- -- --
70: -- -- -- -- -- -- -- --
[dmotooka@ *BBB* :/sys/bus/i2c/devices] i2cdetect -r 2
WARNING! This program can confuse your I2C bus, cause data loss and worse!
I will probe file /dev/i2c-2 using read byte commands.
I will probe address range 0x03-0x77.
Continue? [Y/n]
0 1 2 3 4 5 6 7 8 9 a b c d e f
00: -- -- -- -- -- -- -- -- -- -- -- -- --
10: -- -- -- -- -- -- -- -- -- -- -- -- -- -- -- --
20: -- -- -- -- -- -- -- -- -- -- -- -- -- -- -- --
30: -- -- -- -- -- -- -- -- -- -- -- -- -- -- -- --
40: -- -- -- -- -- -- -- -- -- -- -- -- -- -- -- --
50: -- -- -- -- -- -- -- -- -- -- -- -- -- -- -- --
60: -- -- -- -- -- -- -- -- -- -- -- -- -- -- -- --
70: -- -- -- -- -- -- -- --
[dmotooka@ *BBB* :/sys/bus/i2c/devices]
now my dts integration….
[dmotooka@ *BBB* :/sys/bus/i2c/devices] uname -a
Linux beaglebone 4.4.68-moto #2 SMP Sat Jun 24 19:50:53 JST 2017 armv7l GNU/Linux
[dmotooka@ *BBB* :~] i2cdetect -l
i2c-0 | i2c | OMAP I2C adapter | I2C adapter
i2c-2 | i2c | OMAP I2C adapter | I2C adapter
sudo sh -c "echo duper-i2c > /sys/devices/platform/bone_capemgr/slots "
[dmotooka@ *BBB* :~] i2cdetect -l
i2c-0 | i2c | OMAP I2C adapter | I2C adapter
i2c-1 | i2c | OMAP I2C adapter | I2C adapter
i2c-2 | i2c | OMAP I2C adapter | I2C adapter
[dmotooka@ *BBB* :/sys/bus/i2c/devices] ll i2c-*
lrwxrwxrwx 1 root root 0 Jul 1 14:30 i2c-0 -> ../../../devices/platform/ocp/44e0b000.i2c/i2c-0
lrwxrwxrwx 1 root root 0 Jul 1 14:30 i2c-1 -> ../../../devices/platform/ocp/4802a000.i2c/i2c-1
lrwxrwxrwx 1 root root 0 Jul 1 14:30 i2c-2 -> ../../../devices/platform/ocp/4819c000.i2c/i2c-2
[dmotooka@ *BBB* :/sys/bus/i2c/devices] i2cdetect -r 0
WARNING! This program can confuse your I2C bus, cause data loss and worse!
I will probe file /dev/i2c-0 using read byte commands.
I will probe address range 0x03-0x77.
Continue? [Y/n]
0 1 2 3 4 5 6 7 8 9 a b c d e f
00: -- -- -- -- -- -- -- -- -- -- -- -- --
10: -- -- -- -- -- -- -- -- -- -- -- -- -- -- -- --
20: -- -- -- -- UU -- -- -- -- -- -- -- -- -- -- --
30: -- -- -- -- UU -- -- -- -- -- -- -- -- -- -- --
40: -- -- -- -- -- -- -- -- -- -- -- -- -- -- -- --
50: UU -- -- -- -- -- -- -- -- -- -- -- -- -- -- --
60: -- -- -- -- -- -- -- -- -- -- -- -- -- -- -- --
70: UU -- -- -- -- -- -- --
[dmotooka@ *BBB* :/sys/bus/i2c/devices] i2cdetect -r 1
WARNING! This program can confuse your I2C bus, cause data loss and worse!
I will probe file /dev/i2c-1 using read byte commands.
I will probe address range 0x03-0x77.
Continue? [Y/n]
0 1 2 3 4 5 6 7 8 9 a b c d e f
00: -- -- -- -- -- -- -- -- -- -- -- -- --
10: -- -- -- -- -- -- -- -- -- -- -- -- -- -- -- --
20: -- -- -- -- -- -- -- -- -- -- -- -- -- -- -- --
30: -- -- -- -- -- -- -- -- -- -- -- -- -- -- -- --
40: -- -- -- -- -- -- -- -- -- -- -- ^C
[dmotooka@ *BBB* :/sys/bus/i2c/devices] i2cdetect -r 2
WARNING! This program can confuse your I2C bus, cause data loss and worse!
I will probe file /dev/i2c-2 using read byte commands.
I will probe address range 0x03-0x77.
Continue? [Y/n]
0 1 2 3 4 5 6 7 8 9 a b c d e f
00: -- -- -- -- -- -- -- -- -- -- -- -- --
10: -- -- -- -- -- -- -- -- -- -- -- -- -- -- -- --
20: -- -- -- -- -- -- -- -- -- -- -- -- -- -- -- --
30: -- -- -- -- -- -- -- -- -- -- -- -- -- -- -- --
40: -- -- -- -- -- -- -- -- -- -- -- -- -- -- -- --
50: -- -- -- -- UU UU UU UU -- -- -- -- -- -- -- --
60: -- -- -- -- -- -- -- -- -- -- -- -- -- -- -- --
70: -- -- -- -- -- -- -- --
[dmotooka@ *BBB* :/sys/bus/i2c/devices]
[dmotooka@ *BBB* :/sys/devices/platform/bone_capemgr] cat slots
0: PF---- -1
1: PF---- -1
2: PF---- -1
3: PF---- -1
4: P-O-L- 0 Override Board Name,00A0,Override Manuf,duper-i2c
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

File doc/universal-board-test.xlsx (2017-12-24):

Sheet: nes-debug
Universal board ver. 2 result
0000000000000000 8000: 78 SEI
0000000000000001 8001: a2 ff LDX #$ff
0000000000000002 8003: 9a TXS
0000000000000003 8004: 20 30 80 JSR $8030
0000000000000004 8030: a9 00 LDA #$00
0000000000000005 8032: 8d 00 03 STA $0300
0000000000000006 8035: 8d 01 03 STA $0301
0000000000000007 8038: 8d 57 03 STA $0357
0000000000000008 803b: 60 RTS
0000000000000009 8007: 20 9e 8c JSR $8c9e
000000000000000a 8c9e: a9 20 LDA #$20
000000000000000b 8ca0: 8d 02 03 STA $0302
000000000000000c 8ca3: a9 00 LDA #$00
000000000000000d 8ca5: 8d 03 03 STA $0303
000000000000000e 8ca8: a9 00 LDA #$00
000000000000000f 8caa: 8d 00 20 STA $2000
0000000000000010 8cad: 8d 00 03 STA $0300
0000000000000011 8cb0: 8d 01 20 STA $2001
0000000000000012 8cb3: 8d 01 03 STA $0301
0000000000000013 8cb6: a9 3f LDA #$3f
0000000000000014 8cb8: 8d 06 20 STA $2006
0000000000000015 8cbb: a9 00 LDA #$00
0000000000000016 8cbd: 8d 06 20 STA $2006
0000000000000017 8cc0: a2 00 LDX #$00
0000000000000018 8cc2: a0 20 LDY #$20
0000000000000019 8cc4: bd cf 8c LDA $8ccf, x
000000000000001a 8cc7: 8d 07 20 STA $2007
000000000000001b 8cca: e8 INX
000000000000001c 8ccb: 88 DEY
000000000000001d 8ccc: d0 f6 BNE # -10
000000000000001e 8cc4: bd cf 8c LDA $8ccf, x
000000000000001f 8cc7: 8d 07 20 STA $2007
0000000000000020 8cca: e8 INX
0000000000000021 8ccb: 88 DEY
0000000000000022 8ccc: d0 f6 BNE # -10
0000000000000023 8cc4: bd cf 8c LDA $8ccf, x
0000000000000024 8cc7: 8d 07 20 STA $2007
0000000000000025 8cca: e8 INX
0000000000000026 8ccb: 88 DEY
0000000000000027 8ccc: d0 f6 BNE # -10
0000000000000028 8cc4: bd cf 8c LDA $8ccf, x
0000000000000029 8cc7: 8d 07 20 STA $2007
000000000000002a 8cca: e8 INX
000000000000002b 8ccb: 88 DEY
000000000000002c 8ccc: d0 f6 BNE # -10
000000000000002d 8cc4: bd cf 8c LDA $8ccf, x
000000000000002e 8cc7: 8d 07 20 STA $2007
000000000000002f 8cca: e8 INX
0000000000000030 8ccb: 88 DEY
0000000000000031 8ccc: d0 f6 BNE # -10
0000000000000032 8cc4: bd cf 8c LDA $8ccf, x
0000000000000033 8cc7: 8d 07 20 STA $2007
0000000000000034 8cca: e8 INX
0000000000000035 8ccb: 88 DEY
0000000000000036 8ccc: d0 f6 BNE # -10
0000000000000037 8cc4: bd cf 8c LDA $8ccf, x
0000000000000038 8cc7: 8d 07 20 STA $2007
0000000000000039 8cca: e8 INX
000000000000003a 8ccb: 88 DEY
000000000000003b 8ccc: d0 f6 BNE # -10
000000000000003c 8cc4: bd cf 8c LDA $8ccf, x
000000000000003d 8cc7: 8d 07 20 STA $2007
000000000000003e 8cca: e8 INX
000000000000003f 8ccb: 88 DEY
0000000000000040 8ccc: d0 f6 BNE # -10
0000000000000041 8cc4: bd cf 8c LDA $8ccf, x
0000000000000042 8cc7: 8d 07 20 STA $2007
0000000000000043 8cca: e8 INX
0000000000000044 8ccb: 88 DEY
0000000000000045 8ccc: d0 f6 BNE # -10
0000000000000046 8cc4: bd cf 8c LDA $8ccf, x
0000000000000047 8cc7: 8d 07 20 STA $2007
0000000000000048 8cca: e8 INX
0000000000000049 8ccb: 88 DEY
000000000000004a 8ccc: d0 f6 BNE # -10
000000000000004b 8cc4: bd cf 8c LDA $8ccf, x
000000000000004c 8cc7: 8d 07 20 STA $2007
000000000000004d 8cca: e8 INX
000000000000004e 8ccb: 88 DEY
000000000000004f 8ccc: d0 f6 BNE # -10
0000000000000050 8cc4: bd cf 8c LDA $8ccf, x
0000000000000051 8cc7: 8d 07 20 STA $2007
0000000000000052 8cca: e8 INX
0000000000000053 8ccb: 88 DEY
0000000000000054 8ccc: d0 f6 BNE # -10
0000000000000055 8cc4: bd cf 8c LDA $8ccf, x
0000000000000056 8cc7: 8d 07 20 STA $2007
0000000000000057 8cca: e8 INX
0000000000000058 8ccb: 88 DEY
0000000000000059 8ccc: d0 f6 BNE # -10
000000000000005a 8cc4: bd cf 8c LDA $8ccf, x
000000000000005b 8cc7: 8d 07 20 STA $2007
000000000000005c 8cca: e8 INX
000000000000005d 8ccb: 88 DEY
000000000000005e 8ccc: d0 f6 BNE # -10
000000000000005f 8cc4: bd cf 8c LDA $8ccf, x
0000000000000060 8cc7: 8d 07 20 STA $2007
0000000000000061 8cca: e8 INX
0000000000000062 8ccb: 88 DEY
0000000000000063 8ccc: d0 f6 BNE # -10
0000000000000064 8cc4: bd cf 8c LDA $8ccf, x
0000000000000065 8cc7: 8d 07 20 STA $2007
0000000000000066 8cca: e8 INX
0000000000000067 8ccb: 88 DEY
0000000000000068 8ccc: d0 f6 BNE # -10
0000000000000069 8cc4: bd cf 8c LDA $8ccf, x
000000000000006a 8cc7: 8d 07 20 STA $2007
000000000000006b 8cca: e8 INX
000000000000006c 8ccb: 88 DEY
000000000000006d 8ccc: d0 f6 BNE # -10
000000000000006e 8cc4: bd cf 8c LDA $8ccf, x
000000000000006f 8cc7: 8d 07 20 STA $2007
0000000000000070 8cca: e8 INX
0000000000000071 8ccb: 88 DEY
0000000000000072 8ccc: d0 f6 BNE # -10
0000000000000073 8cc4: bd cf 8c LDA $8ccf, x
0000000000000074 8cc7: 8d 07 20 STA $2007
0000000000000075 8cca: e8 INX
0000000000000076 8ccb: 88 DEY
0000000000000077 8ccc: d0 f6 BNE # -10
0000000000000078 8cc4: bd cf 8c LDA $8ccf, x
0000000000000079 8cc7: 8d 07 20 STA $2007
000000000000007a 8cca: e8 INX
000000000000007b 8ccb: 88 DEY
000000000000007c 8ccc: d0 f6 BNE # -10
000000000000007d 8cc4: bd cf 8c LDA $8ccf, x
000000000000007e 8cc7: 8d 07 20 STA $2007
000000000000007f 8cca: e8 INX
0000000000000080 8ccb: 88 DEY
0000000000000081 8ccc: d0 f6 BNE # -10
0000000000000082 8cc4: bd cf 8c LDA $8ccf, x
0000000000000083 8cc7: 8d 07 20 STA $2007
0000000000000084 8cca: e8 INX
0000000000000085 8ccb: 88 DEY
0000000000000086 8ccc: d0 f6 BNE # -10
0000000000000087 8cc4: bd cf 8c LDA $8ccf, x
0000000000000088 8cc7: 8d 07 20 STA $2007
0000000000000089 8cca: e8 INX
000000000000008a 8ccb: 88 DEY
000000000000008b 8ccc: d0 f6 BNE # -10
000000000000008c 8cc4: bd cf 8c LDA $8ccf, x
000000000000008d 8cc7: 8d 07 20 STA $2007
000000000000008e 8cca: e8 INX
000000000000008f 8ccb: 88 DEY
0000000000000090 8ccc: d0 f6 BNE # -10
0000000000000091 8cc4: bd cf 8c LDA $8ccf, x
0000000000000092 8cc7: 8d 07 20 STA $2007
0000000000000093 8cca: e8 INX
0000000000000094 8ccb: 88 DEY
0000000000000095 8ccc: d0 f6 BNE # -10
0000000000000096 8cc4: bd cf 8c LDA $8ccf, x
0000000000000097 8cc7: 8d 07 20 STA $2007
0000000000000098 8cca: e8 INX
0000000000000099 8ccb: 88 DEY
000000000000009a 8ccc: d0 f6 BNE # -10
000000000000009b 8cc4: bd cf 8c LDA $8ccf, x
000000000000009c 8cc7: 8d 07 20 STA $2007
000000000000009d 8cca: e8 INX
000000000000009e 8ccb: 88 DEY
000000000000009f 8ccc: d0 f6 BNE # -10
00000000000000a0 8cc4: bd cf 8c LDA $8ccf, x
00000000000000a1 8cc7: 8d 07 20 STA $2007
00000000000000a2 8cca: e8 INX
00000000000000a3 8ccb: 88 DEY
00000000000000a4 8ccc: d0 f6 BNE # -10
00000000000000a5 8cc4: bd cf 8c LDA $8ccf, x
00000000000000a6 8cc7: 8d 07 20 STA $2007
00000000000000a7 8cca: e8 INX
00000000000000a8 8ccb: 88 DEY
00000000000000a9 8ccc: d0 f6 BNE # -10
00000000000000aa 8cc4: bd cf 8c LDA $8ccf, x
00000000000000ab 8cc7: 8d 07 20 STA $2007
00000000000000ac 8cca: e8 INX
00000000000000ad 8ccb: 88 DEY
00000000000000ae 8ccc: d0 f6 BNE # -10
00000000000000af 8cc4: bd cf 8c LDA $8ccf, x
00000000000000b0 8cc7: 8d 07 20 STA $2007
00000000000000b1 8cca: e8 INX
00000000000000b2 8ccb: 88 DEY
00000000000000b3 8ccc: d0 f6 BNE # -10
00000000000000b4 8cc4: bd cf 8c LDA $8ccf, x
00000000000000b5 8cc7: 8d 07 20 STA $2007
00000000000000b6 8cca: e8 INX
00000000000000b7 8ccb: 88 DEY
00000000000000b8 8ccc: d0 f6 BNE # -10
00000000000000b9 8cce: 60 RTS
00000000000000ba 800a: 20 e1 8b JSR $8be1
00000000000000bb 8be1: ad ef 8c LDA $8cef
00000000000000bc 8be4: 85 00 STA $00
00000000000000bd 8be6: ad f0 8c LDA $8cf0
00000000000000be 8be9: 85 01 STA $01
00000000000000bf 8beb: 20 34 8c JSR $8c34
00000000000000c0 8c34: ad 02 03 LDA $0302
00000000000000c1 8c37: 8d 06 20 STA $2006
00000000000000c2 8c3a: ad 03 03 LDA $0303
00000000000000c3 8c3d: 8d 06 20 STA $2006
00000000000000c4 8c40: a0 00 LDY #$00
00000000000000c5 8c42: b1 00 LDA ($00), y
00000000000000c6 8c44: 8d 07 20 STA $2007
00000000000000c7 8c47: f0 04 BEQ # +4
00000000000000c8 8c49: c8 INY
00000000000000c9 8c4a: 4c 42 8c JMP $8c42
00000000000000ca 8c42: b1 00 LDA ($00), y
00000000000000cb 8c44: 8d 07 20 STA $2007
00000000000000cc 8c47: f0 04 BEQ # +4
00000000000000cd 8c49: c8 INY
00000000000000ce 8c4a: 4c 42 8c JMP $8c42
00000000000000cf 8c42: b1 00 LDA ($00), y
00000000000000d0 8c44: 8d 07 20 STA $2007
00000000000000d1 8c47: f0 04 BEQ # +4
00000000000000d2 8c49: c8 INY
00000000000000d3 8c4a: 4c 42 8c JMP $8c42
00000000000000d4 8c42: b1 00 LDA ($00), y
00000000000000d5 8c44: 8d 07 20 STA $2007
00000000000000d6 8c47: f0 04 BEQ # +4
00000000000000d7 8c49: c8 INY
00000000000000d8 8c4a: 4c 42 8c JMP $8c42
00000000000000d9 8c42: b1 00 LDA ($00), y
00000000000000da 8c44: 8d 07 20 STA $2007
00000000000000db 8c47: f0 04 BEQ # +4
00000000000000dc 8c49: c8 INY
00000000000000dd 8c4a: 4c 42 8c JMP $8c42
00000000000000de 8c42: b1 00 LDA ($00), y
00000000000000df 8c44: 8d 07 20 STA $2007
00000000000000e0 8c47: f0 04 BEQ # +4
00000000000000e1 8c49: c8 INY
00000000000000e2 8c4a: 4c 42 8c JMP $8c42
00000000000000e3 8c42: b1 00 LDA ($00), y
00000000000000e4 8c44: 8d 07 20 STA $2007
00000000000000e5 8c47: f0 04 BEQ # +4
00000000000000e6 8c49: c8 INY
00000000000000e7 8c4a: 4c 42 8c JMP $8c42
00000000000000e8 8c42: b1 00 LDA ($00), y
00000000000000e9 8c44: 8d 07 20 STA $2007
00000000000000ea 8c47: f0 04 BEQ # +4
00000000000000eb 8c49: c8 INY
00000000000000ec 8c4a: 4c 42 8c JMP $8c42
00000000000000ed 8c42: b1 00 LDA ($00), y
00000000000000ee 8c44: 8d 07 20 STA $2007
00000000000000ef 8c47: f0 04 BEQ # +4
00000000000000f0 8c49: c8 INY
00000000000000f1 8c4a: 4c 42 8c JMP $8c42
00000000000000f2 8c42: b1 00 LDA ($00), y
00000000000000f3 8c44: 8d 07 20 STA $2007
00000000000000f4 8c47: f0 04 BEQ # +4
00000000000000f5 8c49: c8 INY
00000000000000f6 8c4a: 4c 42 8c JMP $8c42
00000000000000f7 8c42: b1 00 LDA ($00), y
00000000000000f8 8c44: 8d 07 20 STA $2007
00000000000000f9 8c47: f0 04 BEQ # +4
00000000000000fa 8c49: c8 INY
00000000000000fb 8c4a: 4c 42 8c JMP $8c42
00000000000000fc 8c42: b1 00 LDA ($00), y
00000000000000fd 8c44: 8d 07 20 STA $2007
00000000000000fe 8c47: f0 04 BEQ # +4
00000000000000ff 8c49: c8 INY
0000000000000100 8c4a: 4c 42 8c JMP $8c42
0000000000000101 8c42: b1 00 LDA ($00), y
0000000000000102 8c44: 8d 07 20 STA $2007
0000000000000103 8c47: f0 04 BEQ # +4
0000000000000104 8c49: c8 INY
0000000000000105 8c4a: 4c 42 8c JMP $8c42
0000000000000106 8c42: b1 00 LDA ($00), y
0000000000000107 8c44: 8d 07 20 STA $2007
0000000000000108 8c47: f0 04 BEQ # +4
0000000000000109 8c4d: 98 TYA
000000000000010a 8c4e: 29 1f AND #$1f
000000000000010b 8c50: c9 1f CMP #$1f
000000000000010c 8c52: f0 09 BEQ # +9
000000000000010d 8c54: a9 00 LDA #$00
000000000000010e 8c56: 8d 07 20 STA $2007
000000000000010f 8c59: c8 INY
0000000000000110 8c5a: 4c 4d 8c JMP $8c4d
0000000000000111 8c4d: 98 TYA
0000000000000112 8c4e: 29 1f AND #$1f
0000000000000113 8c50: c9 1f CMP #$1f
0000000000000114 8c52: f0 09 BEQ # +9
0000000000000115 8c54: a9 00 LDA #$00
0000000000000116 8c56: 8d 07 20 STA $2007
0000000000000117 8c59: c8 INY
0000000000000118 8c5a: 4c 4d 8c JMP $8c4d
0000000000000119 8c4d: 98 TYA
000000000000011a 8c4e: 29 1f AND #$1f
000000000000011b 8c50: c9 1f CMP #$1f
000000000000011c 8c52: f0 09 BEQ # +9
000000000000011d 8c54: a9 00 LDA #$00
000000000000011e 8c56: 8d 07 20 STA $2007
000000000000011f 8c59: c8 INY
0000000000000120 8c5a: 4c 4d 8c JMP $8c4d
0000000000000121 8c4d: 98 TYA
0000000000000122 8c4e: 29 1f AND #$1f
0000000000000123 8c50: c9 1f CMP #$1f
0000000000000124 8c52: f0 09 BEQ # +9
0000000000000125 8c54: a9 00 LDA #$00
0000000000000126 8c56: 8d 07 20 STA $2007
0000000000000127 8c59: c8 INY
0000000000000128 8c5a: 4c 4d 8c JMP $8c4d
0000000000000129 8c4d: 98 TYA
000000000000012a 8c4e: 29 1f AND #$1f
000000000000012b 8c50: c9 1f CMP #$1f
000000000000012c 8c52: f0 09 BEQ # +9
000000000000012d 8c54: a9 00 LDA #$00
000000000000012e 8c56: 8d 07 20 STA $2007
000000000000012f 8c59: c8 INY
0000000000000130 8c5a: 4c 4d 8c JMP $8c4d
0000000000000131 8c4d: 98 TYA
0000000000000132 8c4e: 29 1f AND #$1f
0000000000000133 8c50: c9 1f CMP #$1f
0000000000000134 8c52: f0 09 BEQ # +9
0000000000000135 8c54: a9 00 LDA #$00
0000000000000136 8c56: 8d 07 20 STA $2007
0000000000000137 8c59: c8 INY
0000000000000138 8c5a: 4c 4d 8c JMP $8c4d
0000000000000139 8c4d: 98 TYA
000000000000013a 8c4e: 29 1f AND #$1f
000000000000013b 8c50: c9 1f CMP #$1f
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

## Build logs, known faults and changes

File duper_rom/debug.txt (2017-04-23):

#b 802d
b 9071
d3 on
d4 on
#d5 on
c
q
b 8f36
c
b 802d
c
b 8f36
q

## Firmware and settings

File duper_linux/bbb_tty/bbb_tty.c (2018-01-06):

#include <linux/init.h>
#include <linux/kernel.h>
#include <linux/console.h>
#include <linux/tty.h>
#include <linux/tty_driver.h>
#include <linux/tty_flip.h>
#include <linux/kthread.h>
#include <linux/sched.h>
#include <linux/semaphore.h>

#include "bbb_tty.h"

#define BT_FIFO_SIZE    256
#define NES_LF          0x8a


/*forward declarations...*/
static int nes_tty_write(struct tty_struct * tty, const unsigned char *buf, int count);
static int nes_tty_write_room(struct tty_struct *tty);
static int nes_tty_install(struct tty_driver *drv, struct tty_struct *tty);
static void nes_tty_cleanup(struct tty_struct *tty);
static int nes_tty_open(struct tty_struct *tty, struct file *file);
static void nes_tty_close(struct tty_struct *tty, struct file *file);
static void nes_tty_hangup(struct tty_struct *tty);
static void nes_console_write (struct console *co, const char *str, unsigned int count);
static struct tty_driver *nes_console_device(struct console *co, int *idx);
static int nes_console_setup(struct console *cp, char *arg);


/*static variables...*/
static const struct tty_port_operations bt_port_ops = { };

static struct tty_port    bbb_tty_port;

static struct tty_driver *bbb_tty_driver;

static const struct tty_operations nes_tty_ops = {
    .write      = nes_tty_write,
    .write_room = nes_tty_write_room,
    .install    = nes_tty_install,
    .cleanup    = nes_tty_cleanup,
    .open       = nes_tty_open,
    .close      = nes_tty_close,
    .hangup     = nes_tty_hangup,
};

static struct console nes_console_driver = {
    .name       = "ttynes",
    .write      = nes_console_write,
    .device     = nes_console_device,
    .setup      = nes_console_setup,
    .flags      = CON_PRINTBUFFER,
    .index      = -1,
};

static struct task_struct *bt_thread;
static struct semaphore gpio_sem;
static int received_gpio;

/*implementations...*/

static void bbb_tty_receiver(unsigned char ch) {
    int ret;

/*
    printk(KERN_INFO "receiver: bbb_tty_port.count %d\n", bbb_tty_port.count);
    printk(KERN_INFO "receiver: bbb_tty_port.buf.head %p\n", bbb_tty_port.buf.head);
    printk(KERN_INFO "receiver: bbb_tty_port.buf.tail %p\n", bbb_tty_port.buf.tail);
*/
    if (bbb_tty_port.count == 0) {
        /*tty is not open.*/
        return;
    }

    if (ch == NES_LF) {
        ch = '\n';
    }
    ret = tty_insert_flip_char(&bbb_tty_port, ch, TTY_NORMAL);
    if (ret != 1) {
        printk(KERN_INFO "tty_insert_filp failed. [%c]\n", ch);
    }
    tty_flip_buffer_push(&bbb_tty_port);
}

void bbb_tty_notify(int irq) {
    received_gpio = bt_irq2gpio(irq);
    up(&gpio_sem);
}

static int bt_data_recv_func(void *arg) {

    __set_current_state(TASK_RUNNING);
    printk(KERN_INFO "kthread started.\n");
    while (!kthread_should_stop()) {
        /*wait for interrupt...*/
        down(&gpio_sem);
        if (kthread_should_stop()) break;

        /*printk(KERN_INFO "recgpio %d.\n", received_gpio);*/
        if (received_gpio == GPIO_BBB_FIFO_EMPTY) {
            while (!get_bbb_fifo_empty()) {
                char ch = bt_i2c_getchr();
                /*printk(KERN_INFO "getch %c.\n", ch);*/
                bbb_tty_receiver(ch);
            }
        }
        /*CONFIG_HZ=250
        schedule_timeout_interruptible(HZ);*/
    }
    printk(KERN_INFO "kthread done.\n");

    return 0;
}

static int nes_tty_write(struct tty_struct * tty, const unsigned char *buf, int count) {
    int i;

    //printk("nes_tty_write start.count:%d.\n", count);
    for (i = 0; i < count; i++) {
        int res;
        res = bt_i2c_putchr(buf[i]);
        if (!res)
            break;
    }
    //printk("nes_tty_write done.i:%d.\n", i);
    return i;
}

static int nes_tty_write_room(struct tty_struct *tty) {
        return BT_FIFO_SIZE;
}

static int nes_tty_install(struct tty_driver *drv, struct tty_struct *tty) {
    int ret;

    tty_port_init(&bbb_tty_port);
    bbb_tty_port.ops = &bt_port_ops;

    ret = tty_port_install(&bbb_tty_port, drv, tty);
    if (ret) {
        printk(KERN_INFO "tty_port_install failed.\n");
        return ret;
    }
/*
    printk(KERN_INFO "install: bbb_tty_port.buf.head %p\n", bbb_tty_port.buf.head);
    printk(KERN_INFO "install: bbb_tty_port.buf.tail %p\n", bbb_tty_port.buf.tail);
*/
    return 0;
}

static void nes_tty_cleanup(struct tty_struct *tty) {
    tty_port_destroy(&bbb_tty_port);
}

static int nes_tty_open(struct tty_struct *tty, struct file *file) {
    tty_port_tty_set(&bbb_tty_port, tty);
    return tty_port_open(&bbb_tty_port, tty, file);
}

static void nes_tty_close(struct tty_struct *tty, struct file *file) {
    tty_port_tty_set(&bbb_tty_port, NULL);
    tty_port_close(&bbb_tty_port, tty, file);
}

static void nes_tty_hangup(struct tty_struct *tty) {
    tty_port_hangup(&bbb_tty_port);
}


static void nes_console_write (struct console *co, const char *str, unsigned int count) {
    while (count--) {
        bt_i2c_putchr( *str++ );
    }
}

static struct tty_driver *nes_console_device(struct console *co, int *idx) {
    *idx = co->index;
    return bbb_tty_driver;
}

static int nes_console_setup(struct console *cp, char *arg) {
    return 0;
}

int __init bbb_tty_init(void){
    int ret;

    printk(KERN_INFO "bbb_tty init.\n");

    received_gpio = 0;
    sema_init(&gpio_sem, 0);

    bt_thread = kthread_create(bt_data_recv_func, NULL, "ttynes_th");
    if (!bt_thread) {
        printk(KERN_INFO "failed to craete kernel thread.\n");
        return -1;
    }
    wake_up_process(bt_thread);

    bbb_tty_driver = alloc_tty_driver(1);
    if (!bbb_tty_driver) {
        printk(KERN_INFO "tty driver allocation error.\n");
        return -ENOMEM;
    }

    bbb_tty_driver->driver_name     = "bbb_tty_driver";
    bbb_tty_driver->name            = "ttyNES";
    bbb_tty_driver->num             = 1;
    bbb_tty_driver->type            = TTY_DRIVER_TYPE_SERIAL;
    bbb_tty_driver->subtype         = SERIAL_TYPE_NORMAL;
    bbb_tty_driver->flags           = TTY_DRIVER_REAL_RAW;
    bbb_tty_driver->init_termios    = tty_std_termios;

    tty_set_operations(bbb_tty_driver, &nes_tty_ops);
    tty_port_link_device(&bbb_tty_port, bbb_tty_driver, 0);
    ret = tty_register_driver(bbb_tty_driver);
    if (ret) {
        printk(KERN_ERR "tty driver registration failed.\n");
        return -1;
    }

    register_console(&nes_console_driver);

    return 0;
}

void __exit bbb_tty_exit(void){
    unregister_console(&nes_console_driver);
    tty_unregister_driver(bbb_tty_driver);
    put_tty_driver(bbb_tty_driver);
    up(&gpio_sem);
    kthread_stop(bt_thread);

    printk(KERN_INFO "bbb_tty exit.\n");
}

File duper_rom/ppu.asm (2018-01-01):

.setcpu        "6502"
.autoimport    on

.export update_screen
.export main_screen_init
.export char_test
.export init_menu
.export init_ppu
.export jp_status

;;for debugging..
.export scroll_next

.segment "STARTUP"


;;;screen func table.
update_funcs:
    .addr   main_screen_updt        ;0
    .addr   inet_screen_updt        ;1
    .addr   game_screen_updt        ;2
    .addr   shell_screen_updt       ;3
    .addr   inet_bmark_scr_updt     ;4
    .addr   inet_srch_scr_updt      ;5
    .addr   inet_dirct_scr_updt     ;6
    .word   $00

.proc update_screen
    ;;;get current screen stat.
    lda screen_status
    asl     ;;offset address to word.
    tay
    lda update_funcs, y ;;get handler low.
    sta $02
    iny
    lda update_funcs, y ;;get handler hi
    sta $03

    ;;goto handler.
    jmp ($02)
.endproc


;;;init func table.
init_funcs:
    .addr   main_screen_init        ;0
    .addr   inet_screen_init        ;1
    .addr   game_screen_init        ;2
    .addr   shell_screen_init       ;3
    .addr   inet_bmark_scr_init     ;4
    .addr   inet_srch_scr_init      ;5
    .addr   inet_dirct_scr_init     ;6
    .word   $00

.proc init_screen
    ;;;get current screen stat.
    lda screen_status
    asl     ;;offset address to word.
    tay
    lda init_funcs, y ;;get handler low.
    sta $02
    iny
    lda init_funcs, y ;;get handler hi
    sta $03

    ;;goto handler.
    jmp ($02)
.endproc

.proc main_screen_updt
    ;;;case up
    lda #$10
    bit jp1_data
    beq @down

    lda #1
    cmp top_menu_select
    bne :+
    jmp @end
:
    ;;move cursor up.
    lda top_menu_cur_pos
    sta $02
    lda top_menu_cur_pos+1
    sta $03
    lda un_select_cursor
    sta $00
    lda un_select_cursor+1
    sta $01
    jsr print_str

    sec
    lda #$20
    sta $00
    lda top_menu_cur_pos+1
    sbc $00
    sta top_menu_cur_pos+1
    sta $03

    lda #$00
    sta $00
    lda top_menu_cur_pos
    sbc $00
    sta top_menu_cur_pos
    sta $02

    lda select_cursor
    sta $00
    lda select_cursor+1
    sta $01
    jsr print_str
    
    ;;decrement selected index.
    dec top_menu_select
    
    ;;invalidate jp input for a while.
    lda #$00
    sta jp_status

    jmp @end

@down:
    ;;case down
    lda #$20
    bit jp1_data
    beq @a

    lda #3
    cmp top_menu_select
    beq @end

    ;;move cursor down.
    lda top_menu_cur_pos
    sta $02
    lda top_menu_cur_pos+1
    sta $03
    lda un_select_cursor
    sta $00
    lda un_select_cursor+1
    sta $01
    jsr print_str

    clc
    lda #$20
    adc top_menu_cur_pos+1
    sta top_menu_cur_pos+1
    sta $03
    lda #$00
    adc top_menu_cur_pos
    sta top_menu_cur_pos
    sta $02

    lda select_cursor
    sta $00
    lda select_cursor+1
    sta $01
    jsr print_str
    
    ;;increment selected index.
    inc top_menu_select

    ;;invalidate jp input for a while.
    lda #$00
    sta jp_status

    jmp @end

@a:
    ;;case a
    lda #$01
    bit jp1_data
    beq @end

    lda top_menu_select
    sta screen_status   ;;navigate to next screen.

    jsr init_screen

    ;;invalidate jp input for a while.
    lda #$00
    sta jp_status

@end:
    rts
.endproc

.proc inet_screen_updt
    ;;;case up
    lda #$10
    bit jp1_data
    beq @down

    lda #4
    cmp inet_menu_select
    bne :+
    jmp @end
:
    ;;move cursor up.
    lda inet_menu_cur_pos
    sta $02
    lda inet_menu_cur_pos+1
    sta $03
    lda un_select_cursor
    sta $00
    lda un_select_cursor+1
    sta $01
    jsr print_str

    sec
    lda #$20
    sta $00
    lda inet_menu_cur_pos+1
    sbc $00
    sta inet_menu_cur_pos+1
    sta $03

    lda #$00
    sta $00
    lda inet_menu_cur_pos
    sbc $00
    sta inet_menu_cur_pos
    sta $02

    lda select_cursor
    sta $00
    lda select_cursor+1
    sta $01
    jsr print_str

    ;;increment selected index.
    dec inet_menu_select

    ;;invalidate jp input for a while.
    lda #$00
    sta jp_status

    jmp @end

@down:
    ;;case down
    lda #$20
    bit jp1_data
    beq @a

    lda #7
    cmp inet_menu_select
    beq @end

    ;;move cursor down.
    lda inet_menu_cur_pos
    sta $02
    lda inet_menu_cur_pos+1
    sta $03
    lda un_select_cursor
    sta $00
    lda un_select_cursor+1
    sta $01
    jsr print_str

    clc
    lda #$20
    adc inet_menu_cur_pos+1
    sta inet_menu_cur_pos+1
    sta $03
    lda #$00
    adc inet_menu_cur_pos
    sta inet_menu_cur_pos
    sta $02

    lda select_cursor
    sta $00
    lda select_cursor+1
    sta $01
    jsr print_str

    ;;increment selected index.
    inc inet_menu_select

    ;;invalidate jp input for a while.
    lda #$00
    sta jp_status

    jmp @end

@a:
    ;;case a
    lda #$01
    bit jp1_data
    beq @end

    lda #7
    cmp inet_menu_select
    bne :+
    ;;case return.
    jsr main_screen_init
    jmp @next_page_done
:
    lda inet_menu_select
    sta screen_status   ;;navigate to next screen.
    jsr init_screen
@next_page_done:
    ;;invalidate jp input for a while.
    lda #$00
    sta jp_status

@end:

    rts
.endproc

.proc inet_bmark_scr_updt
    ;;;case up
    lda #$10
    bit jp1_data
    beq @down

    lda #0
    cmp bmark_menu_select
    bne :+
    jmp @end
:
    ;;move cursor up.
    lda bmark_menu_cur_pos
    sta $02
    lda bmark_menu_cur_pos+1
    sta $03
    lda un_select_cursor
    sta $00
    lda un_select_cursor+1
    sta $01
    jsr print_str

    sec
    lda #$20
    sta $00
    lda bmark_menu_cur_pos+1
    sbc $00
    sta bmark_menu_cur_pos+1
    sta $03

    lda #$00
    sta $00
    lda bmark_menu_cur_pos
    sbc $00
    sta bmark_menu_cur_pos
    sta $02

    lda select_cursor
    sta $00
    lda select_cursor+1
    sta $01
    jsr print_str

    ;;increment selected index.
    dec bmark_menu_select

    ;;invalidate jp input for a while.
    lda #$00
    sta jp_status

    jmp @end

@down:
    ;;case down
    lda #$20
    bit jp1_data
    beq @a

    lda #4
    cmp bmark_menu_select
    bne :+
    jmp @end
:
    ;;move cursor down.
    lda bmark_menu_cur_pos
    sta $02
    lda bmark_menu_cur_pos+1
    sta $03
    lda un_select_cursor
    sta $00
    lda un_select_cursor+1
    sta $01
    jsr print_str

    clc
    lda #$20
    adc bmark_menu_cur_pos+1
    sta bmark_menu_cur_pos+1
    sta $03
    lda #$00
    adc bmark_menu_cur_pos
    sta bmark_menu_cur_pos
    sta $02

    lda select_cursor
    sta $00
    lda select_cursor+1
    sta $01
    jsr print_str

    ;;increment selected index.
    inc bmark_menu_select

    ;;invalidate jp input for a while.
    lda #$00
    sta jp_status

    jmp @end
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

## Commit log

2016-10-25 architecture diagram added
    [super-duper-nes-architecture.xlsx]
2016-10-26 test rom created.
    [linker.cfg]
2016-10-27 chr rom working.
    [super-duper-display-image.xlsx]
2016-10-28 bg pixel ok.
    [super-duper-display-image.xlsx]
2016-10-28 top menu created
    [super-duper-display-image.xlsx]
2016-10-28 menu screen created.
    [linker.cfg]
2016-10-28 h/w design doc added
    [super-duper-nes-hardware-design.xlsx]
2016-10-29 nmi handler added
    [super-duper-display-image.xlsx]
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2016-11-01 keyboard update
    [super-duper-display-image.xlsx]
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2016-11-22 nes <-> fpga inter-connect doc added.
    [nes-fpga-inter-connect.xlsx]
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2016-12-18 doc update
    [item-lists.xlsx]
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2016-12-25 bread board simulation check.
    [33-voltage-protection-check.xlsx]
2017-01-03 test doc update
    [33-voltage-protection-check.xlsx, nes-fpga-inter-connect.xlsx]
2017-01-03 level shift test specification created.
    [nes-fpga-inter-connect.xlsx]
2017-01-03 level shifter test fpga logic ok.
    [nes-fpga-inter-connect.xlsx]
2017-01-08 level shifter doc updated
    [33-voltage-protection-check.xlsx, nes-fpga-inter-connect.xlsx, super-duper-nes-hardware-design.xlsx]
2017-01-08 slow down count up.
    [33-voltage-protection-check.xlsx]
2017-01-08 logic analyzer test ok.
    [33-voltage-protection-check.xlsx, level_shift_test01.stp, level_shift_test01_auto_stripped.stp]
2017-01-08 board layout first ver ok.
    [super-duper-nes-hardware-design.xlsx]
2017-01-09 addr bus to be diode.
    [super-duper-nes-hardware-design.xlsx]
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2017-01-28 universal board inter-connect doc update
    [33-voltage-protection-check.xlsx, nes-fpga-inter-connect.xlsx, super-duper-nes-hardware-design.xlsx]
2017-01-28 test doc renamed.
    [universal-board-test.xlsx]
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2017-01-29 first nes connection test. rom /ce seems not coming... must investigate.
    [rom_test01.stp, rom_test01_auto_stripped.stp, universal-board-test.xlsx]
2017-02-12 irq vector added.
    [universal-board-test.xlsx]
2017-02-12 swapped pin assignment.
    [universal-board-test.xlsx]
2017-02-12 doc updated.
    [super-duper-nes-hardware-design.xlsx, universal-board-test.xlsx]
2017-02-26 new universasl board doc update.
    [universal-board-test.xlsx]
2017-02-26 pin asignment updated.
    [universal-board-test.xlsx]
2017-02-26 rom debug..
    [universal-board-test.xlsx]
2017-02-26 rom 8k update.
    [linker.cfg]
2017-02-26 still debugging..
    [universal-board-test.xlsx]
2017-03-04 wrong pin assignment fixed.
    [universal-board-test.xlsx]
2017-03-04 version 0.1 ok!!
    [universal-board-test.xlsx]
2017-03-13 ppu pin asignment updated.
    [super-duper-nes-hardware-design.xlsx, universal-board-test.xlsx]
2017-03-18 ppu enabled board vhdl updated.
    [rom_test01.stp, universal-board-test.xlsx]
2017-03-19 my first hacked rom test ok!!
    [rom_test01.stp, universal-board-test.xlsx]
2017-03-19 work evidence pics uploaded.
    [rom_test01_auto_stripped.stp]
2017-03-25 debug pins and regs added.
    [universal-board-test.xlsx]
2017-03-25 Micrated to DE0 CV board due to mamory array restrictions.
    [universal-board-test.xlsx]
2017-03-26 more work...
    [universal-board-test.xlsx]
2017-04-01 still work...
    [rom_test01.stp, rom_test01_auto_stripped.stp]
2017-04-01 nmi ok, but ppu bg display make whole things fucked up...
    [rom_test01_de0_cv.stp, rom_test01_de0_cv_auto_stripped.stp]
2017-04-02 show bg makes it fucked up...
    [universal-board-test.xlsx]
2017-04-09 bringing up board, still working...
    [universal-board-test.xlsx]
2017-04-23 wrong pin asignment fixed.
    [universal-board-test.xlsx]
2017-04-23 simplified board...
    [universal-board-test.xlsx]
2017-04-30 finally universal board test ok!!!
    [rom_test01.stp, rom_test01_auto_stripped.stp, rom_test01_de0_cv.stp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]
2017-05-01 ppu a11 and cram a10 desciption.
    [universal-board-test.xlsx]
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2017-06-25 i2c work doc update
    [i2c-test-doc.xlsx]
2017-07-01 added bbb i2c dts!
    [i2c-test-doc.xlsx]
2017-07-01 update i2c fpga.
    [i2c-test-doc.xlsx]
2017-07-06 i2c-1 eeprom test okgit add i2c-test-doc.xlsx
    [i2c-test-doc.xlsx]
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2017-08-05 i2c stop cmd bug fixed.
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2017-08-27 i2c communication ok!! read bug still exists, but overall it's working!
2017-09-10 new env work setup...
    [universal-board-test.xlsx]
2017-09-23 fifo doc and vhdl created.
    [super-duper-nes-architecture.xlsx]
2017-09-30 dir renamed.
    [linker.cfg]
2017-09-30 pop fifo rom working...
    [duper_cartridge.stp, super-duper-display-image.xlsx]
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2017-11-20 character code doc update.
    [super-duper-display-image.xlsx]
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2017-11-23 modelsim simulation work update.
    [super-duper-nes-architecture.xlsx]
2017-11-24 modelsim dev env, rom integration ok.
    [super-duper-nes-architecture.xlsx]
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2017-11-25 fifo state machine working.
    [super-duper-nes-architecture.xlsx]
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2017-11-26 i2c input emulation working.
    [super-duper-nes-architecture.xlsx]
2017-11-26 more i2c rework...
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2017-12-03 nes push fifo oookey.
    [super-duper-nes-architecture.xlsx]
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2017-12-06 bbb i2c rd working.
    [super-duper-nes-architecture.xlsx]
2017-12-07 bbb i2c read ok.
    [super-duper-nes-architecture.xlsx]
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2017-12-10 doesn't work...
    [duper_cartridge.stp]
2017-12-12 nes target test ok, pio pin direction has the problem. must repair...
2017-12-13 latest vhdl image ok! fifo seems not working tho, lol
    [duper_cartridge.stp]
2017-12-16 fifo status read bug fixed. bbb2nes xfer ok! (i2c sometimes went silent, lol)
2017-12-17 code clean up. thanks to physical power button no need logical reset.
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2017-12-23 i2c xfer all ok!
    [super-duper-nes-architecture.xlsx]
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2017-12-31 empty text input bug fixed.
    [ppu.asm]
2017-12-31 i2c data recv proc optimizing..
    [super-duper-nes-architecture.xlsx]
2018-01-01 i2c send timing bug fixed.
    [ppu.asm]
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2018-01-03 not working yet. kernel can't prove the device.
    [bt_i2c.c]
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2018-01-04 i2c memo update. (custom dts has error... must rework. currently walk around using i2c2 bus.)
    [super-duper-nes-architecture.xlsx]
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
